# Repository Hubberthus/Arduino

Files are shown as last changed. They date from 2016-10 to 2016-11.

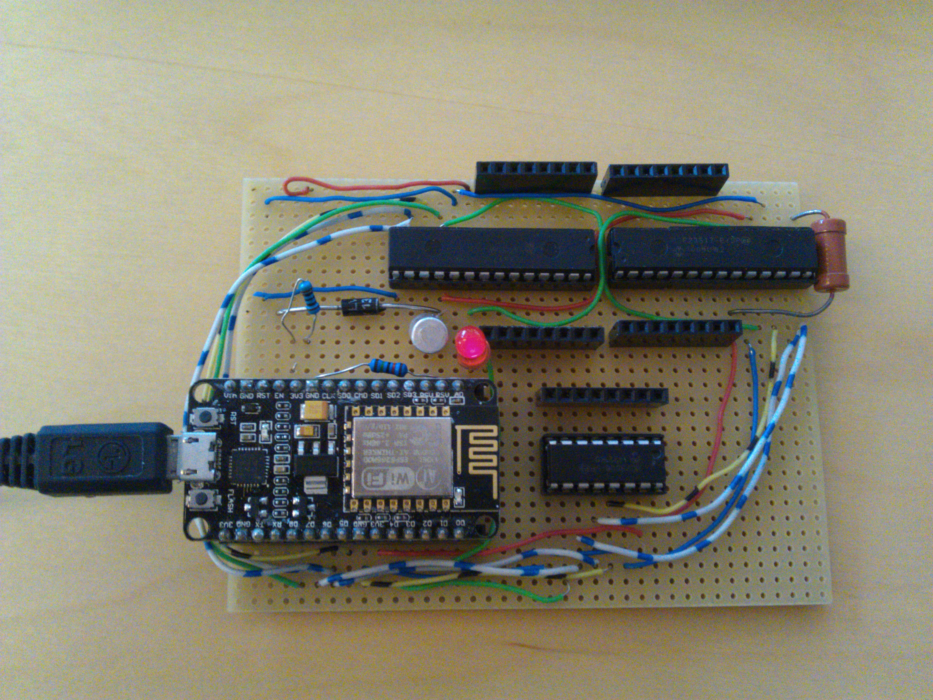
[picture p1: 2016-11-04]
variants/espextra/ESPExtra-0.1.1-stripboard.jpg

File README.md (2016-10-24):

Arduino core for ESPExtra module based on the "Arduino core for ESP8266 WiFi chip" project
==========================================================================================

This fork contains an additional module called ESPExtra, which is an ESP8266-based module using MCP23S17 and MCP3008 ICs to allow the usage of additional 32 digital GPIO and 8 analog input pins.
It can be accessed in the "espextra" branch.

The ESPExtra appears as a new variant which you can choose in Arduino IDE.
It contains several modifications in the ESP8266 core code, mostly for digital and analog GPIO access. The additional pins can be set/read/written using the standard Arduino functions.

Generally it can be used simply as an Arduino board, just look out for the pin numbering because most of the ESP8266's pins are for internal usage only. Please use the A0...A8, D0...D31 and CS_0...CS_2 constants for accessing the GPIOs.

For more information about the usage of the ESPExtra, please look at the Wiki page:
(https://github.com/Hubberthus/ESPExtra/wiki)

Below is the original "README.md" file:
(TODO: Update installation information)

Arduino core for ESP8266 WiFi chip
===========================================

This project brings support for ESP8266 chip to the Arduino environment. It lets you write sketches using familiar Arduino functions and libraries, and run them directly on ESP8266, no external microcontroller required.

ESP8266 Arduino core comes with libraries to communicate over WiFi using TCP and UDP, set up HTTP, mDNS, SSDP, and DNS servers, do OTA updates, use a file system in flash memory, work with SD cards, servos, SPI and I2C peripherals.

# Contents
- Installing options:
  - [Using Boards Manager](#installing-with-boards-manager)
  - [Using git version](#using-git-version)
  - [Using PlatformIO](#using-platformio)
  - [Building with make](#building-with-make)
- [Documentation](#documentation)
- [Issues and support](#issues-and-support)
- [Contributing](#contributing)  
- [License and credits](#license-and-credits)   

### Installing with Boards Manager ###

Starting with 1.6.4, Arduino allows installation of third-party platform packages using Boards Manager. We have packages available for Windows, Mac OS, and Linux (32 and 64 bit).

- Install Arduino 1.6.8 from the [Arduino website](http://www.arduino.cc/en/main/software).
- Start Arduino and open Preferences window.
- Enter ```http://arduino.esp8266.com/stable/package_esp8266com_index.json``` into *Additional Board Manager URLs* field. You can add multiple URLs, separating them with commas.
- Open Boards Manager from Tools > Board menu and install *esp8266* platform (and don't forget to select your ESP8266 board from Tools > Board menu after installation).

The best place to ask questions related to this core is ESP8266 community forum: http://www.esp8266.com/arduino.
If you find this forum or the ESP8266 Boards Manager package useful, please consider supporting it with a donation. <br />


#### Available versions

##### Stable version 
Boards manager link: `http://arduino.esp8266.com/stable/package_esp8266com_index.json`

Documentation: [http://esp8266.github.io/Arduino/versions/2.3.0/](http://esp8266.github.io/Arduino/versions/2.3.0/)

##### Staging version 
Boards manager link: `http://arduino.esp8266.com/staging/package_esp8266com_index.json`

Documentation: [http://esp8266.github.io/Arduino/versions/2.3.0-rc2/](http://esp8266.github.io/Arduino/versions/2.3.0-rc2/)

### Using git version
 

- Install Arduino 1.6.8
- Go to Arduino directory
- Clone this repository into hardware/esp8266com/esp8266 directory (or clone it elsewhere and create a symlink)
```bash
cd hardware
mkdir esp8266com
cd esp8266com
git clone https://github.com/esp8266/Arduino.git esp8266
```
- Download binary tools (you need Python 2.7)
```bash
cd esp8266/tools
python get.py
```
- Restart Arduino

### Using PlatformIO

[PlatformIO](http://platformio.org) is an open source ecosystem for IoT
development with cross platform build system, library manager and full support
for Espressif (ESP8266) development. It works on the popular host OS: Mac OS X, Windows,
Linux 32/64, Linux ARM (like Raspberry Pi, BeagleBone, CubieBoard).

- [What is PlatformIO?](http://docs.platformio.org/en/stable/what-is-platformio.html)
- [PlatformIO IDE](http://platformio.org/platformio-ide)
- Quick Start with [PlatformIO IDE](http://docs.platformio.org/en/stable/ide/atom.html#quick-start) or [PlatformIO CLI](http://docs.platformio.org/en/stable/quickstart.html)
- [Advanced using](http://docs.platformio.org/en/stable/platforms/espressif.html) -
  custom settings, uploading to SPIFFS, Over-the-Air (OTA) or using stage version
- [Integration with other IDE](http://docs.platformio.org/en/stable/ide.html) -
  Atom, CLion, Eclipse, Emacs, NetBeans, Qt Creator, Sublime Text, VIM and Visual Studio
- [Project Examples](http://docs.platformio.org/en/stable/platforms/espressif.html#examples)

### Building with make

[makeEspArduino](https://github.com/plerup/makeEspArduino) is a generic makefile for any ESP8266 Arduino project.
Using make instead of the Arduino IDE makes it easier to do automated and production builds.

### Documentation

Documentation for latest development version:

- [Reference](doc/reference.md)
- [Libraries](doc/libraries.md)
- [File system](doc/filesystem.md)
- [OTA update](doc/ota_updates/readme.md)
- [Supported boards](doc/boards.md)
- [FAQ / Trubleshooting](doc/faq/readme.md)
- [Change log](doc/changes.md)

### Issues and support ###

If you encounter an issue, you are welcome to submit it here on Github: https://github.com/esp8266/Arduino/issues.
Please provide as much context as possible: version which you are using (you can check it in Boards Manager), your sketch code, serial output, board model, IDE settings (board selection, flash size, etc).

If you can not find the answers above, you can also try [ESP8266 Community Forum](http://www.esp8266.com/arduino)

### Contributing

For minor fixes of code and documentation, go ahead and submit a pull request.

Check out the list of issues which are easy to fix — [easy issues for 2.2.0](https://github.com/esp8266/Arduino/issues?q=is%3Aopen+is%3Aissue+milestone%3A2.2.0+label%3A%22level%3A+easy%22). Working on them is a great way to move the project forward.

Larger changes (rewriting parts of existing code from scratch, adding new functions to the core, adding new libraries) should generally be discussed [in the chat](https://gitter.im/esp8266/Arduino) first.

Feature branches with lots of small commits (especially titled "oops", "fix typo", "forgot to add file", etc.) should be squashed before opening a pull request. At the same time, please refrain from putting multiple unrelated changes into a single pull request.

### License and credits ###

Arduino IDE is developed and maintained by the Arduino team. The IDE is licensed under GPL.

ESP8266 core includes an xtensa gcc toolchain, which is also under GPL.

Esptool written by Christian Klippel is licensed under GPLv2, currently maintained by Ivan Grokhotkov: https://github.com/igrr/esptool-ck.

Espressif SDK included in this build is under Espressif MIT License.

ESP8266 core files are licensed under LGPL.

[SPI Flash File System (SPIFFS)](https://github.com/pellepl/spiffs) written by Peter Andersson is used in this project. It is distributed under MIT license.

[umm_malloc](https://github.com/rhempel/umm_malloc) memory management library written by Ralph Hempel is used in this project. It is distributed under MIT license.

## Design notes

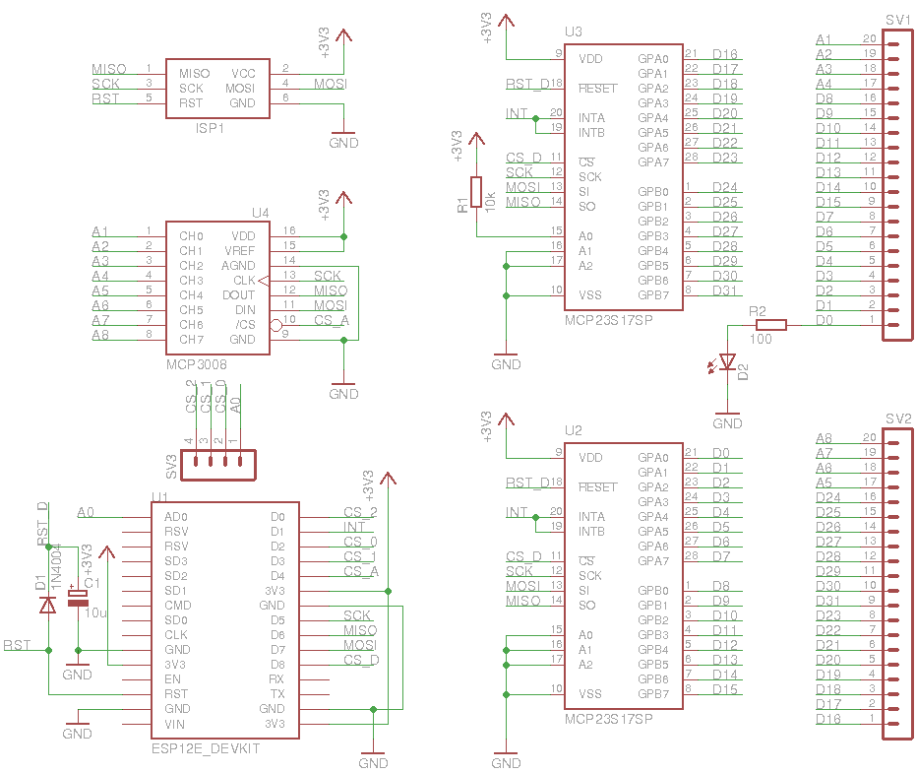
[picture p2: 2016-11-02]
variants/espextra/ESPExtra-0.1.1.png

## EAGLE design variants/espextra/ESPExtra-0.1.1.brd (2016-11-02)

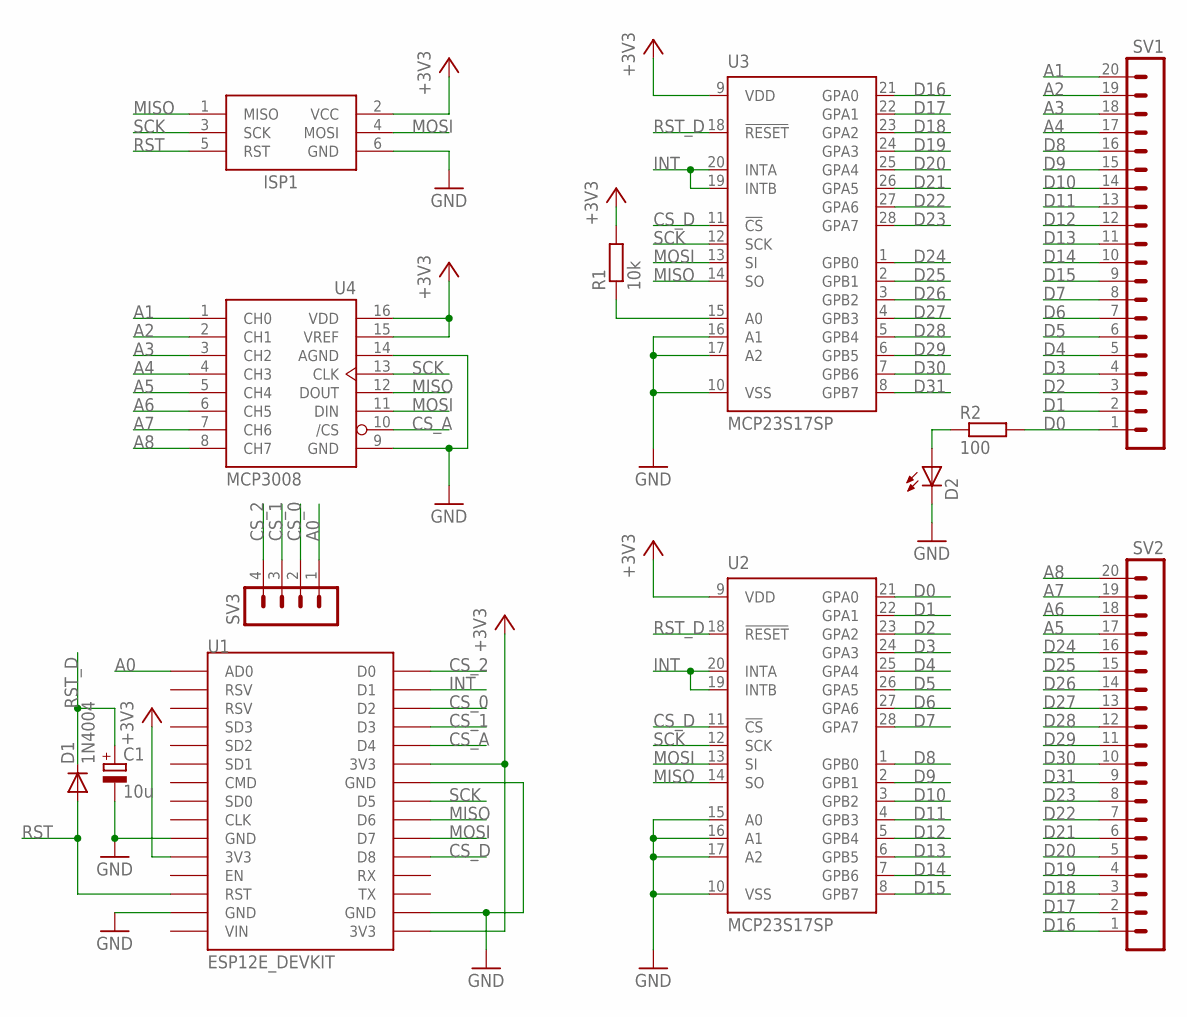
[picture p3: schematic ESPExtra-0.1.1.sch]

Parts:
C1: 10u; E2,5-5
D1: 1N4004; DO41-10
D2: LED3MM
ISP1: AVRISP-6; AVRISP
R1: 10k; 0204/5
R2: 100; 0204/5
SV1, SV2: MA20-1
SV3: MA04-1
U1: ESP12E_DEVKIT
U2, U3: MCP23S17SP; DIL28-3
U4: MCP3008; DIL16

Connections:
+3V3: ISP1.2 (VCC), R1.2, U1.3V3@0 (3V3), U1.3V3@1 (3V3), U1.3V3@2 (3V3), U2.9 (VDD), U3.9 (VDD), U4.15 (VREF), U4.16 (VDD)
A0: SV3.1, U1.AD0
A1: SV1.20, U4.1 (CH0)
A2: SV1.19, U4.2 (CH1)
A3: SV1.18, U4.3 (CH2)
A4: SV1.17, U4.4 (CH3)
A5: SV2.17, U4.5 (CH4)
A6: SV2.18, U4.6 (CH5)
A7: SV2.19, U4.7 (CH6)
A8: SV2.20, U4.8 (CH7)
CS_0: SV3.2, U1.D2
CS_1: SV3.3, U1.D3
CS_2: SV3.4, U1.D0
CS_A: U1.D4, U4.10 (/CS)
CS_D: U1.D8, U2.11 (!CS), U3.11 (!CS)
D0: R2.2, SV1.1, U2.21 (GPA0)
D1: SV1.2, U2.22 (GPA1)
D2: SV1.3, U2.23 (GPA2)
D3: SV1.4, U2.24 (GPA3)
D4: SV1.5, U2.25 (GPA4)
D5: SV1.6, U2.26 (GPA5)
D6: SV1.7, U2.27 (GPA6)
D7: SV1.8, U2.28 (GPA7)
D8: SV1.16, U2.1 (GPB0)
D9: SV1.15, U2.2 (GPB1)
D10: SV1.14, U2.3 (GPB2)
D11: SV1.13, U2.4 (GPB3)
D12: SV1.12, U2.5 (GPB4)
D13: SV1.11, U2.6 (GPB5)
D14: SV1.10, U2.7 (GPB6)
D15: SV1.9, U2.8 (GPB7)
D16: SV2.1, U3.21 (GPA0)
D17: SV2.2, U3.22 (GPA1)
D18: SV2.3, U3.23 (GPA2)
D19: SV2.4, U3.24 (GPA3)
D20: SV2.5, U3.25 (GPA4)
D21: SV2.6, U3.26 (GPA5)
D22: SV2.7, U3.27 (GPA6)
D23: SV2.8, U3.28 (GPA7)
D24: SV2.16, U3.1 (GPB0)
D25: SV2.15, U3.2 (GPB1)
D26: SV2.14, U3.3 (GPB2)
D27: SV2.13, U3.4 (GPB3)
D28: SV2.12, U3.5 (GPB4)
D29: SV2.11, U3.6 (GPB5)
D30: SV2.10, U3.7 (GPB6)
D31: SV2.9, U3.8 (GPB7)
GND: C1.-, D2.K (C), ISP1.6 (GND), U1.GND@0 (GND), U1.GND@1 (GND), U1.GND@2 (GND), U1.GND@3 (GND), U2.10 (VSS), U2.15 (A0), U2.16 (A1), U2.17 (A2), U3.10 (VSS), U3.16 (A1), U3.17 (A2), U4.9 (GND), U4.14 (AGND)
INT: U1.D1, U2.19 (INTB), U2.20 (INTA), U3.19 (INTB), U3.20 (INTA)
MISO: ISP1.1 (MISO), U1.D6, U2.14 (SO), U3.14 (SO), U4.12 (DOUT)
MOSI: ISP1.4 (MOSI), U1.D7, U2.13 (SI), U3.13 (SI), U4.11 (DIN)
unnamed: D2.A, R2.1
unnamed: R1.1, U3.15 (A0)
RST: D1.A, ISP1.5 (RST), U1.RST
RST_D: C1.+, D1.C, U2.18 (!RESET), U3.18 (!RESET)
SCK: ISP1.3 (SCK), U1.D5, U2.12 (SCK), U3.12 (SCK), U4.13 (CLK)

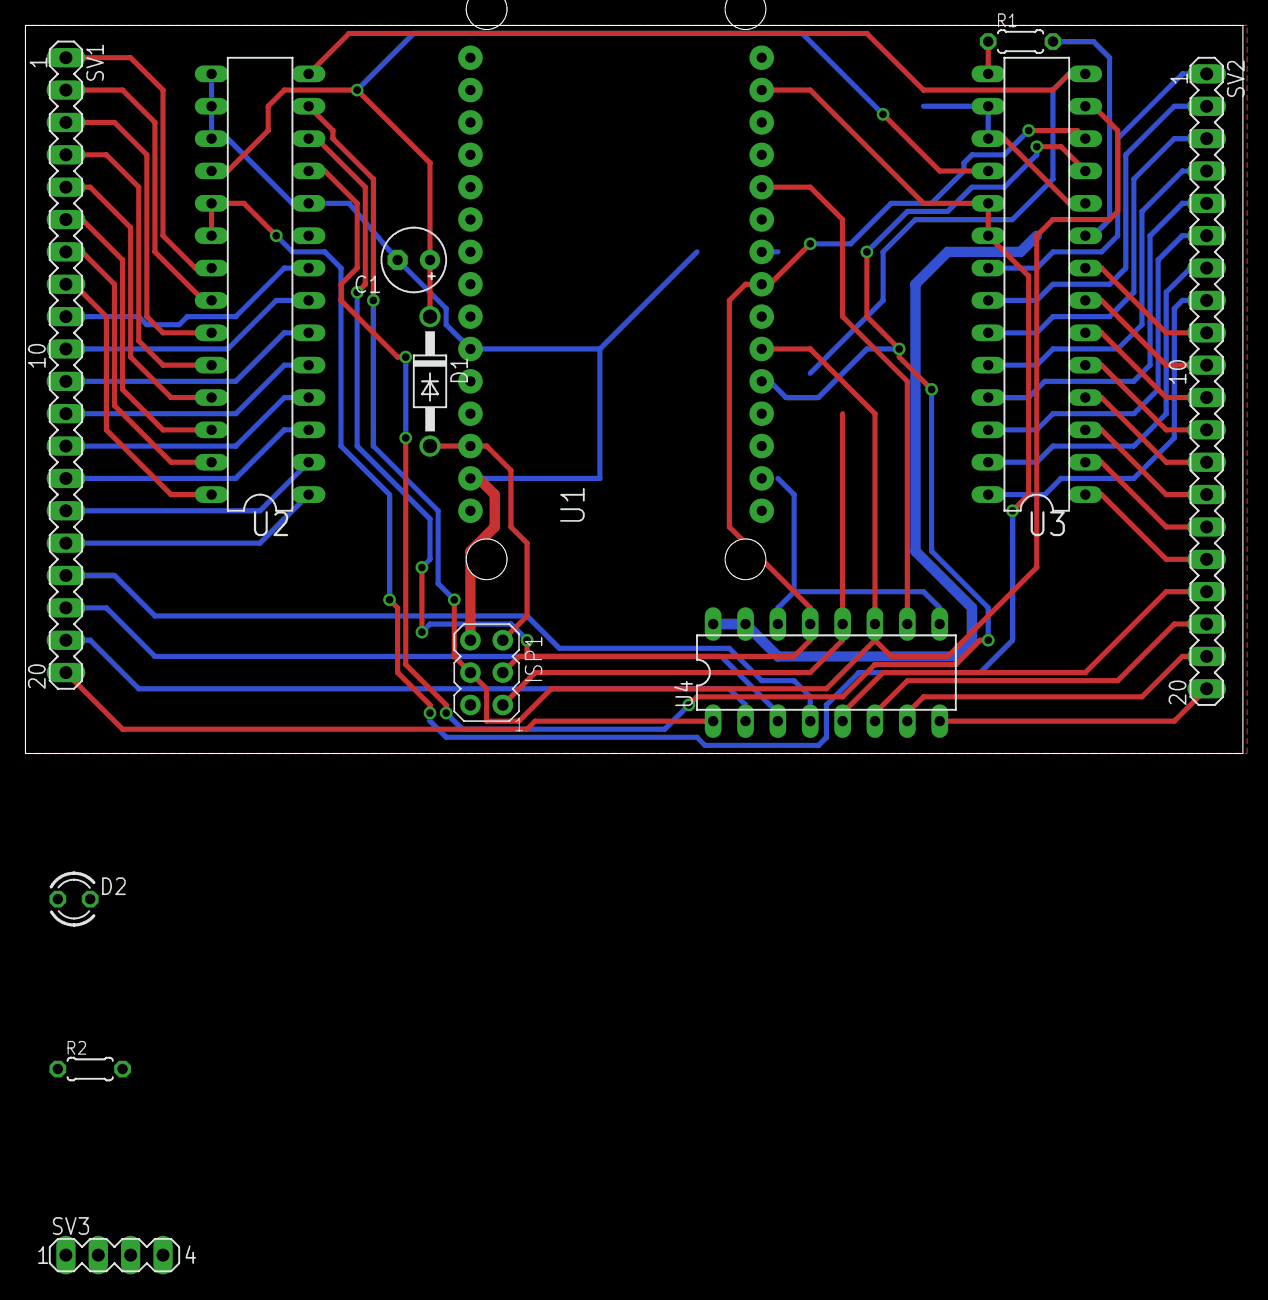
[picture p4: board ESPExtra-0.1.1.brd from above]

Board: 2 copper layers, 95.6 x 57.1 mm, 13 parts (0 on the bottom side), 56 nets.

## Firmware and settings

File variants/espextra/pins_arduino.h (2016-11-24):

/*
  pins_arduino.h - Pin definition functions for Arduino
  Part of Arduino - http://www.arduino.cc/

  Copyright (c) 2007 David A. Mellis
  Modified for ESPExtra variant by Norbert Fekete, 2016.

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
  $Id: wiring.h 249 2007-02-03 16:52:51Z mellis $
*/

#ifndef Pins_Arduino_h
#define Pins_Arduino_h

#include "../generic/common.h"

#ifdef __cplusplus
extern "C" {
#endif

#define NUM_EXTERNAL_DIGITAL_PINS  32
#define NUM_INTERNAL_DIGITAL_PINS  17
#define NUM_DIGITAL_PINS           (NUM_INTERNAL_DIGITAL_PINS + NUM_EXTERNAL_DIGITAL_PINS)
#define NUM_EXTERNAL_ANALOG_INPUTS 8
#define NUM_INTERNAL_ANALOG_INPUTS 1
#define NUM_ANALOG_INPUTS          (NUM_INTERNAL_ANALOG_INPUTS + NUM_EXTERNAL_ANALOG_INPUTS)
#define NUM_INTERNAL_PINS          (NUM_INTERNAL_DIGITAL_PINS + NUM_INTERNAL_ANALOG_INPUTS)

#define digitalPinHasPWM(p)        (((p) >= NUM_INTERNAL_PINS && (p) < NUM_DIGITAL_PINS + NUM_INTERNAL_ANALOG_INPUTS)? 1 : 0)
#define digitalPinToInterrupt(p)   (((p) < EXTERNAL_NUM_INTERRUPTS) || digitalPinHasPWM(p)? (p) : NOT_AN_INTERRUPT)

#define digitalPinToPort(pin)       (((pin) < NUM_INTERNAL_PINS ? 0 : \
		((pin) < NUM_DIGITAL_PINS + NUM_INTERNAL_ANALOG_INPUTS ? PORT_LIST[0] : 0)))
#define digitalPinToBitMask(pin)    ((pin) < NUM_INTERNAL_PINS ? 1UL << (pin) : 1 << (pin - NUM_INTERNAL_PINS))
#define digitalPinToTimer(pin)      ((pin) < NUM_INTERNAL_PINS ? 0 : -1)
#define portOutputRegister(port)    ((pin) < NUM_INTERNAL_PINS ? (volatile uint32_t*) &GPO : PORT_LIST[0])
#define portInputRegister(port)     ((pin) < NUM_INTERNAL_PINS ? (volatile uint32_t*) &GPI : PORT_LIST[0])
#define portModeRegister(port)      ((pin) < NUM_INTERNAL_PINS ? (volatile uint32_t*) &GPE : PORT_LIST[0])

// ESP8266 pins

#define CS_MCP23S17  15  // D8: TX1/HCS (pull down on boot)
#define CS_MCP3008    2  // D4: bootstrap TX/blue LED (pull up on boot)
#define CS_0          4  // D2
#define CS_1          0  // D3: flash (pull up on boot)
#define CS_2         16  // D0: user/wake/red LED

#define INT_GPIO      5  // D1

#define SDA           4  // CS_0 / D2
#define SCL           0  // CS_1 / D3

// Expanded pins

#define LED_BUILTIN  (NUM_INTERNAL_PINS)
#define BUILTIN_LED  (NUM_INTERNAL_PINS)

// PORTA
#define D0  (NUM_INTERNAL_PINS)
#define D1  (NUM_INTERNAL_PINS + 1)
#define D2  (NUM_INTERNAL_PINS + 2)
#define D3  (NUM_INTERNAL_PINS + 3)
#define D4  (NUM_INTERNAL_PINS + 4)
#define D5  (NUM_INTERNAL_PINS + 5)
#define D6  (NUM_INTERNAL_PINS + 6)
#define D7  (NUM_INTERNAL_PINS + 7)
// PORTB
#define D8   (NUM_INTERNAL_PINS + 8)
#define D9   (NUM_INTERNAL_PINS + 9)
#define D10  (NUM_INTERNAL_PINS + 10)
#define D11  (NUM_INTERNAL_PINS + 11)
#define D12  (NUM_INTERNAL_PINS + 12)
#define D13  (NUM_INTERNAL_PINS + 13)
#define D14  (NUM_INTERNAL_PINS + 14)
#define D15  (NUM_INTERNAL_PINS + 15)
// PORTC
#define D16  (NUM_INTERNAL_PINS + 16)
#define D17  (NUM_INTERNAL_PINS + 17)
#define D18  (NUM_INTERNAL_PINS + 18)
#define D19  (NUM_INTERNAL_PINS + 19)
#define D20  (NUM_INTERNAL_PINS + 20)
#define D21  (NUM_INTERNAL_PINS + 21)
#define D22  (NUM_INTERNAL_PINS + 22)
#define D23  (NUM_INTERNAL_PINS + 23)
// PORTD
#define D24  (NUM_INTERNAL_PINS + 24)
#define D25  (NUM_INTERNAL_PINS + 25)
#define D26  (NUM_INTERNAL_PINS + 26)
#define D27  (NUM_INTERNAL_PINS + 27)
#define D28  (NUM_INTERNAL_PINS + 28)
#define D29  (NUM_INTERNAL_PINS + 29)
#define D30  (NUM_INTERNAL_PINS + 30)
#define D31  (NUM_INTERNAL_PINS + 31)

#define A1  (NUM_DIGITAL_PINS + NUM_INTERNAL_ANALOG_INPUTS)
#define A2  (NUM_DIGITAL_PINS + NUM_INTERNAL_ANALOG_INPUTS + 1)
#define A3  (NUM_DIGITAL_PINS + NUM_INTERNAL_ANALOG_INPUTS + 2)
#define A4  (NUM_DIGITAL_PINS + NUM_INTERNAL_ANALOG_INPUTS + 3)
#define A5  (NUM_DIGITAL_PINS + NUM_INTERNAL_ANALOG_INPUTS + 4)
#define A6  (NUM_DIGITAL_PINS + NUM_INTERNAL_ANALOG_INPUTS + 5)
#define A7  (NUM_DIGITAL_PINS + NUM_INTERNAL_ANALOG_INPUTS + 6)
#define A8  (NUM_DIGITAL_PINS + NUM_INTERNAL_ANALOG_INPUTS + 7)

#ifdef __cplusplus
} // extern "C"
#endif

#endif /* Pins_Arduino_h */

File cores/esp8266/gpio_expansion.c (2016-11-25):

#ifdef ARDUINO_ESP_EXTRA

#include "Arduino.h"
#include "gpio_expansion.h"
#include "gpio_exp_devs.h"

#ifdef __cplusplus
extern "C" {
#endif

volatile uint32_t PORT_VAL = 0;
volatile uint32_t PORT_DIR = 0xFFFFFFFF;
volatile uint32_t PORT_PUUP = 0;
volatile uint32_t PORT_INT = 0;
volatile uint32_t PORT_INT_CON = 0;
volatile uint32_t PORT_INT_DEFVAL = 0;

#define PORTA_INT ((uint8_t*)&PORT_INT)[0]
#define PORTB_INT ((uint8_t*)&PORT_INT)[1]
#define PORTC_INT ((uint8_t*)&PORT_INT)[2]
#define PORTD_INT ((uint8_t*)&PORT_INT)[3]

#define PORTA_INT_CON ((uint8_t*)&PORT_INT_CON)[0]
#define PORTB_INT_CON ((uint8_t*)&PORT_INT_CON)[1]
#define PORTC_INT_CON ((uint8_t*)&PORT_INT_CON)[2]
#define PORTD_INT_CON ((uint8_t*)&PORT_INT_CON)[3]

#define PORTA_INT_DEFVAL ((uint8_t*)&PORT_INT_DEFVAL)[0]
#define PORTB_INT_DEFVAL ((uint8_t*)&PORT_INT_DEFVAL)[1]
#define PORTC_INT_DEFVAL ((uint8_t*)&PORT_INT_DEFVAL)[2]
#define PORTD_INT_DEFVAL ((uint8_t*)&PORT_INT_DEFVAL)[3]

typedef struct {
  uint8_t mode;
  void (*fn)(void);
} interrupt_handler_t;

static interrupt_handler_t PORT_INT_FUNC[NUM_EXTERNAL_DIGITAL_PINS];

void _gpio_expansion_startup() {
	_mcp23s17_init(CS_MCP23S17);
	_mcp3008_init(CS_MCP3008);
	pinMode(INT_GPIO, INPUT_PULLUP);
}

void gpio_expansion_flush() {

	uint32_t savedPS = xt_rsil(15); // stop other interrupts

	_mcp23s17_transaction_start();

	if (PORTA_DIR != 0xFF) _mcp23s17_setA(0, PORTA);
	if (PORTB_DIR != 0xFF) _mcp23s17_setB(0, PORTB);
	if (PORTC_DIR != 0xFF) _mcp23s17_setA(1, PORTC);
	if (PORTD_DIR != 0xFF) _mcp23s17_setB(1, PORTD);

	xt_wsr_ps(savedPS);
}

void _gpio_expansion_pinMode(uint8_t pin, uint8_t mode) {

	uint32_t savedPS = xt_rsil(15); // stop other interrupts
	uint32_t mask = 0;

	if ((mode != INPUT) && (mode != OUTPUT) && (mode != INPUT_PULLUP)) {
		xt_wsr_ps(savedPS);
		return;
	}

	pin -= NUM_INTERNAL_PINS;

	if (pin >= NUM_EXTERNAL_DIGITAL_PINS) {
		xt_wsr_ps(savedPS);
		return;
	}

	mask = (1 << pin);

	_mcp23s17_transaction_start();

	switch(pin >> 3) {
	case 0:
		if (mode == OUTPUT) {
			PORT_DIR &= ~mask;
			PORT_INT &= ~mask;
			interrupt_handler_t *handler = &PORT_INT_FUNC[pin];
			handler->mode = 0;
			handler->fn = NULL;
			_mcp23s17_setReg(0, MCP23S17_IODIRA, PORTA_DIR);
			_mcp23s17_setReg(0, MCP23S17_GPINTENA, PORTA_INT);
			_mcp23s17_setA(0, PORTA);
		} else {
			PORT_DIR |= mask;
			_mcp23s17_setReg(0, MCP23S17_IODIRA, PORTA_DIR);
			if (mode == INPUT_PULLUP) {
				PORT_PUUP |= mask;
			} else {
				PORT_PUUP &= ~mask;
			}
			_mcp23s17_setReg(0, MCP23S17_GPPUA, PORTA_PUUP);
			PORT_VAL &= ~mask;
			PORT_VAL |= (_mcp23s17_getA(0) & mask);
		}
		break;
	case 1:
		if (mode == OUTPUT) {
			PORT_DIR &= ~mask;
			PORT_INT &= ~mask;
			interrupt_handler_t *handler = &PORT_INT_FUNC[pin];
			handler->mode = 0;
			handler->fn = NULL;
			_mcp23s17_setReg(0, MCP23S17_IODIRB, PORTB_DIR);
			_mcp23s17_setReg(0, MCP23S17_GPINTENB, PORTB_INT);
			_mcp23s17_setB(0, PORTB);
		} else {
			PORT_DIR |= mask;
			_mcp23s17_setReg(0, MCP23S17_IODIRB, PORTB_DIR);
			if (mode == INPUT_PULLUP) {
				PORT_PUUP |= mask;
			} else {
				PORT_PUUP &= ~mask;
			}
			_mcp23s17_setReg(0, MCP23S17_GPPUB, PORTB_PUUP);
			PORT_VAL &= ~mask;
			PORT_VAL |= ((_mcp23s17_getB(0) << 8) & mask);
		}
		break;
	case 2:
		if (mode == OUTPUT) {
			PORT_DIR &= ~mask;
			PORT_INT &= ~mask;
			interrupt_handler_t *handler = &PORT_INT_FUNC[pin];
			handler->mode = 0;
			handler->fn = NULL;
			_mcp23s17_setReg(1, MCP23S17_IODIRA, PORTC_DIR);
			_mcp23s17_setReg(1, MCP23S17_GPINTENA, PORTC_INT);
			_mcp23s17_setA(1, PORTC);
		} else {
			PORT_DIR |= mask;
			_mcp23s17_setReg(1, MCP23S17_IODIRA, PORTC_DIR);
			if (mode == INPUT_PULLUP) {
				PORT_PUUP |= mask;
			} else {
				PORT_PUUP &= ~mask;
			}
			_mcp23s17_setReg(1, MCP23S17_GPPUA, PORTC_PUUP);
			PORT_VAL &= ~mask;
			PORT_VAL |= ((_mcp23s17_getA(1) << 16) & mask);
		}
		break;
	case 3:
		if (mode == OUTPUT) {
			PORT_DIR &= ~mask;
			PORT_INT &= ~mask;
			interrupt_handler_t *handler = &PORT_INT_FUNC[pin];
			handler->mode = 0;
			handler->fn = NULL;
			_mcp23s17_setReg(1, MCP23S17_IODIRB, PORTD_DIR);
			_mcp23s17_setReg(1, MCP23S17_GPINTENB, PORTD_INT);
			_mcp23s17_setB(1, PORTD);
		} else {
			PORT_DIR |= mask;
			_mcp23s17_setReg(1, MCP23S17_IODIRB, PORTD_DIR);
			if (mode == INPUT_PULLUP) {
				PORT_PUUP |= mask;
			} else {
				PORT_PUUP &= ~mask;
			}
			_mcp23s17_setReg(1, MCP23S17_GPPUB, PORTD_PUUP);
			PORT_VAL &= ~mask;
			PORT_VAL |= ((_mcp23s17_getB(1) << 24) & mask);
		}
		break;
	}

	xt_wsr_ps(savedPS);
}
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

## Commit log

2016-10-21 Fixing board identification macros
    [core_esp8266_wiring_digital.c, gpio_expansion.c, mcp23s17.c]
2016-10-25 Board schematics and layout for v0.1
    [ESPExtra-0.1.brd, ESPExtra-0.1.sch]
2016-10-26 Removed unnecessary duplicates from board
2016-10-26 Previous commit failed to update board files
    [ESPExtra-0.1.brd, ESPExtra-0.1.sch]
2016-10-26 After second thought, wrapping the whole 'avr' directory is not relevant. User application should use appropriate alternatives for EEPROM, progmem, interrupts, etc.
2016-10-26 Resistor removed, internal pullup is used for interrupt pin. Also, before SPI transactions, set the appropriate SPI settings, just to be sure.
    [ESPExtra-0.1.brd, ESPExtra-0.1.sch]
2016-11-02 Updated the board schematic to use 3V3. Using 5V is not working.
    [ESPExtra-0.1.1.brd, ESPExtra-0.1.1.sch]
2016-11-04 SPI speedup. Also stripboard image added
2016-11-11 Initial PWM test for ESPExtra. D0-D15 can be used as PWM pins. NMI is not good for the interrupt because of the SPI
2016-11-14 PWM got #define-s, and I2C default pins added
2016-11-15 Some SPI speed optimization and interrupt handling fix
    [core_esp8266_wiring_pwm.c, gpio_exp_devs.c, gpio_expansion.c]
2016-11-15 GPIO interrupt handling added
2016-11-16 GPIO interrupt handling corrections
    [gpio_expansion.c, gpio_expansion.h]
2016-11-16 SPI library includes interrupt handling for transactions. Also HW CS pin usage and SPI ending is disabled for ESPExtra.
2016-11-24 pinMode bugfix + digitalWrite on an input pin sets pullup accordingly
    [gpio_expansion.c]
2016-11-24 Changed pin consts to #defines so they can be used in macros
2016-11-24 Fixed bug: only first 8 digital outputs were working
    [gpio_expansion.c, gpio_expansion.h]
2016-11-25 Interrupt bugfix + flushing of all outputs added
    [gpio_expansion.c, gpio_expansion.h]

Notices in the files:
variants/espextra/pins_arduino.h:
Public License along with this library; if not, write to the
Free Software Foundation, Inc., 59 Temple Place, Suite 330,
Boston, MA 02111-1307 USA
